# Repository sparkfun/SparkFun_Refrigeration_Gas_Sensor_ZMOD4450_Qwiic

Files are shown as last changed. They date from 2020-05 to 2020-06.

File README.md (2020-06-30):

SparkX Refrigeration Gas Sensor - ZMOD4450 (Qwiic)
========================================

SparkX Refrigeration Gas Sensor - ZMOD4450 (Qwiic)

[*SparkX Refrigeration Gas Sensor - ZMOD4450 (Qwiic) (SPX-16677)*](https://www.sparkfun.com/products/16677)

The ZMOD4450 from Renesas is a refrigeration air quality sensor designed to measure gases typically emitted during food ripening and rotting. The sensor measures ethlyene, amines and volatile sulfur compounds and reports the data via I<sup>2</sup>C. This breakout from SparkX uses the Qwiic system to easily add this sensor into your Qwiic chain. 

Feel like supporting open-source hardware? Buy a [board](https://www.sparkfun.com/products/16677) from SparkFun!

Repository Contents
-------------------

* **/Documentation** - Data sheets, additional product information
* **/Firmware** - Target Specific I<sup>2</sup>C and Low Level Functions
* **/Hardware** - Eagle design files (.brd, .sch)
* **/Production** - Production panel files (.brd)

Product Versions
----------------
* [SPX-16677](https://www.sparkfun.com/products/16677)- Original SparkX release of the Refrigeration Gas Sensor - ZMOD4450

License Information
-------------------

This product is _**open source**_! 

Please review the LICENSE.md file for license information. 

If you have any questions or concerns on licensing, please contact technical support on our [SparkFun forums](https://forum.sparkfun.com/viewforum.php?f=152).

Distributed as-is; no warranty is given.

- Your friends at SparkFun.

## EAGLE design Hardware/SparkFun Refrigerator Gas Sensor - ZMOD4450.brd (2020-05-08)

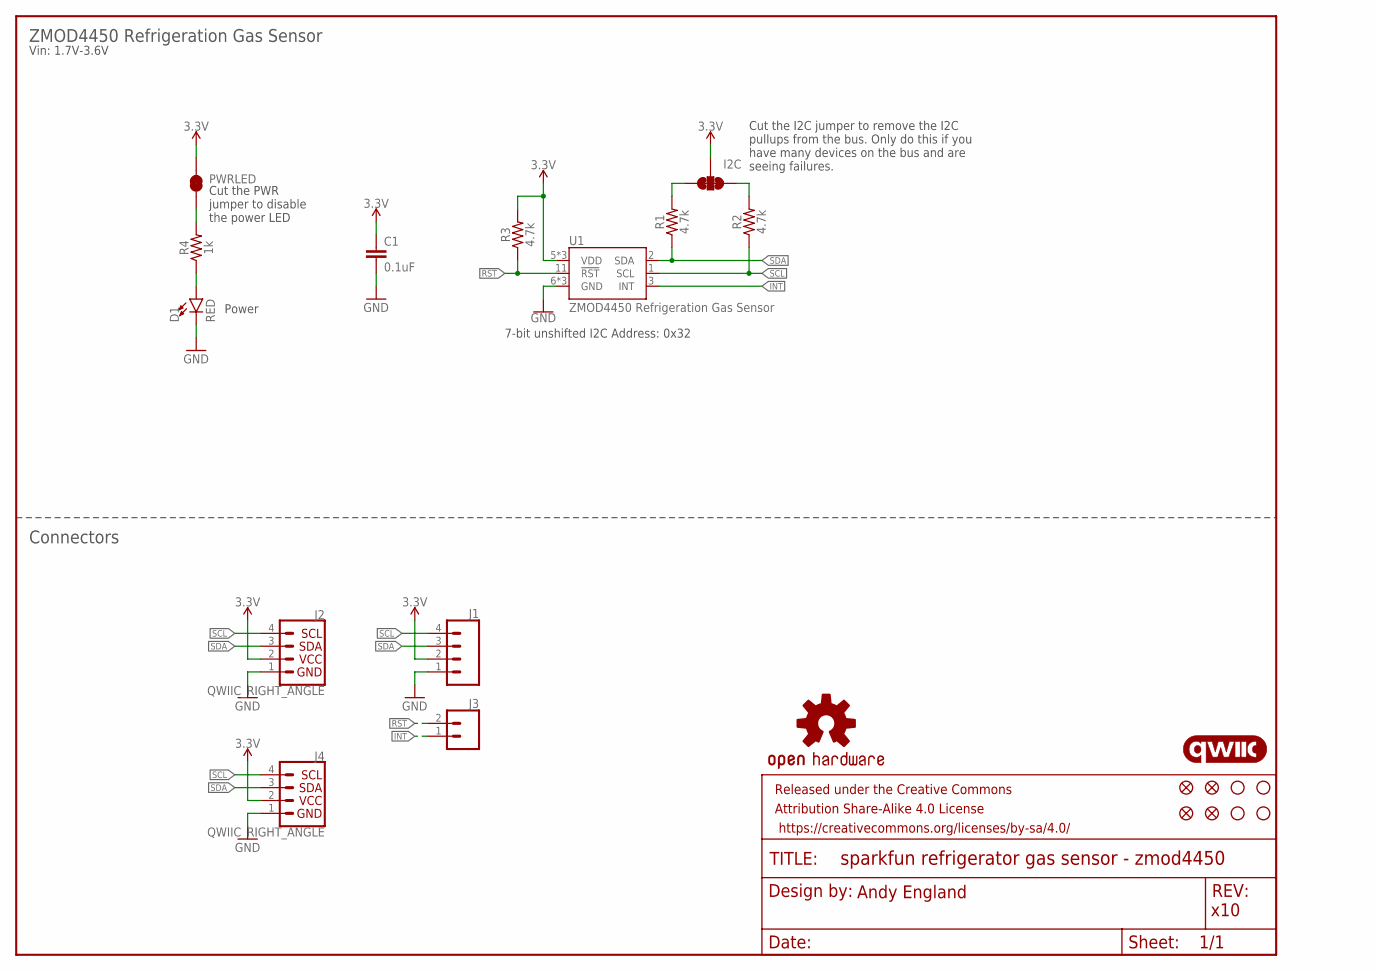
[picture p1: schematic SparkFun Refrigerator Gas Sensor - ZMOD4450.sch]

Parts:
C1: 0.1uF; 0603
D1: RED; LED-0603
FD1, FD2, FD3, FD4: FIDUCIALUFIDUCIAL; FIDUCIAL-MICRO
FRAME1: FRAME-LETTER; CREATIVE_COMMONS
H1, H2, H3, H4: STAND-OFF
I2C: JUMPER-SMT_3_2-NC_TRACE_SILK; SMT-JUMPER_3_2-NC_TRACE_SILK
J1: CONN_041X04_NO_SILK; 1X04_NO_SILK
J2, J4: QWIIC_RIGHT_ANGLE; JST04_1MM_RA
J3: CONN_021X02_NO_SILK; 1X02_NO_SILK
LOGO1: OSHW-LOGOS; OSHW-LOGO-S
LOGO2: QWIIC_LOGO_5MM; QWIIC_5MM
PWRLED: JUMPER-SMT_2_NC_TRACE_SILK; SMT-JUMPER_2_NC_TRACE_SILK
R1, R2, R3: 4.7k; 0603
R4: 1k; 0603
U1: ZMOD4450 Refrigeration Gas Sensor; LGA-12-3X3

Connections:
3.3V: C1.1, I2C.2, J1.2, J2.2, J4.2, PWRLED.2, R3.2, U1.5 (VDD), U1.10 (VDD), U1.12 (VDD)
!RST: J3.2, R3.1, U1.11 (!RST)
GND: C1.2, D1.C, J1.1, J2.1, J4.1, U1.6 (GND), U1.7 (GND), U1.9 (GND)
INT: J3.1, U1.3 (INT)
unnamed: I2C.3, R1.2
unnamed: D1.A, R4.1
unnamed: I2C.1, R2.2
unnamed: PWRLED.1, R4.2
SCL: J1.4, J2.4, J4.4, R2.1, U1.1 (SCL)
SDA: J1.3, J2.3, J4.3, R1.1, U1.2 (SDA)

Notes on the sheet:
Andy England
x10
Power
Connectors
Cut the PWR jumper to disable the power LED
ZMOD4450 Refrigeration Gas Sensor
Vin: 1.7V-3.6V
7-bit unshifted I2C Address: 0x32
Cut the I2C jumper to remove the I2C pullups from the bus. Only do this if you have many devices on the bus and are seeing failures.

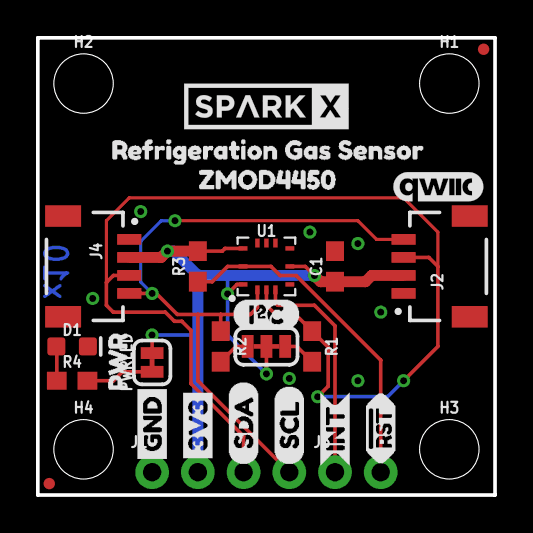
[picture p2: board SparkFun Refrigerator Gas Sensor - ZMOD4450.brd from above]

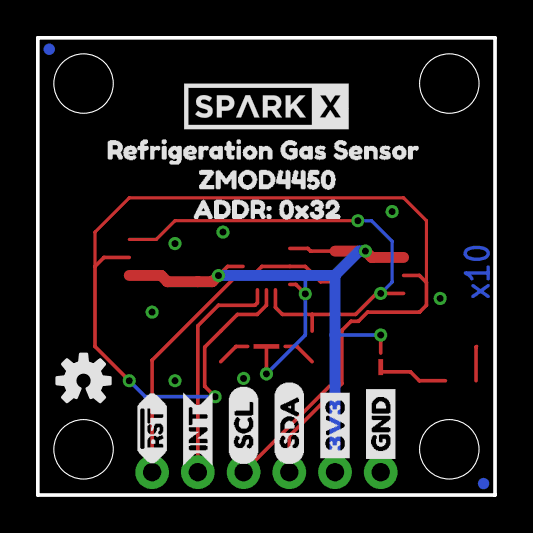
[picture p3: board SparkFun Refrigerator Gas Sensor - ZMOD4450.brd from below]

Board: 2 copper layers, 25.4 x 25.4 mm, 46 parts (13 on the bottom side), 10 nets.

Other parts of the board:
U$1, U$2: GND_P
U$3, U$20: ZMOD44501
U$4, U$14: INT_O
U$5, U$6: 3V3_P
U$7, U$8: SDA_IO
U$9, U$10: SCL_IO
U$11: I2C
U$12: PWR_TO
U$13, U$16: !RST_I
U$15, U$17: REFRIGERATION_GAS_SENSOR0
U$18, U$19: SPARKX-MEDIUM
U$21: ADDR#_0X320
U$22: PRODUCTION_INSTRUCTIONS

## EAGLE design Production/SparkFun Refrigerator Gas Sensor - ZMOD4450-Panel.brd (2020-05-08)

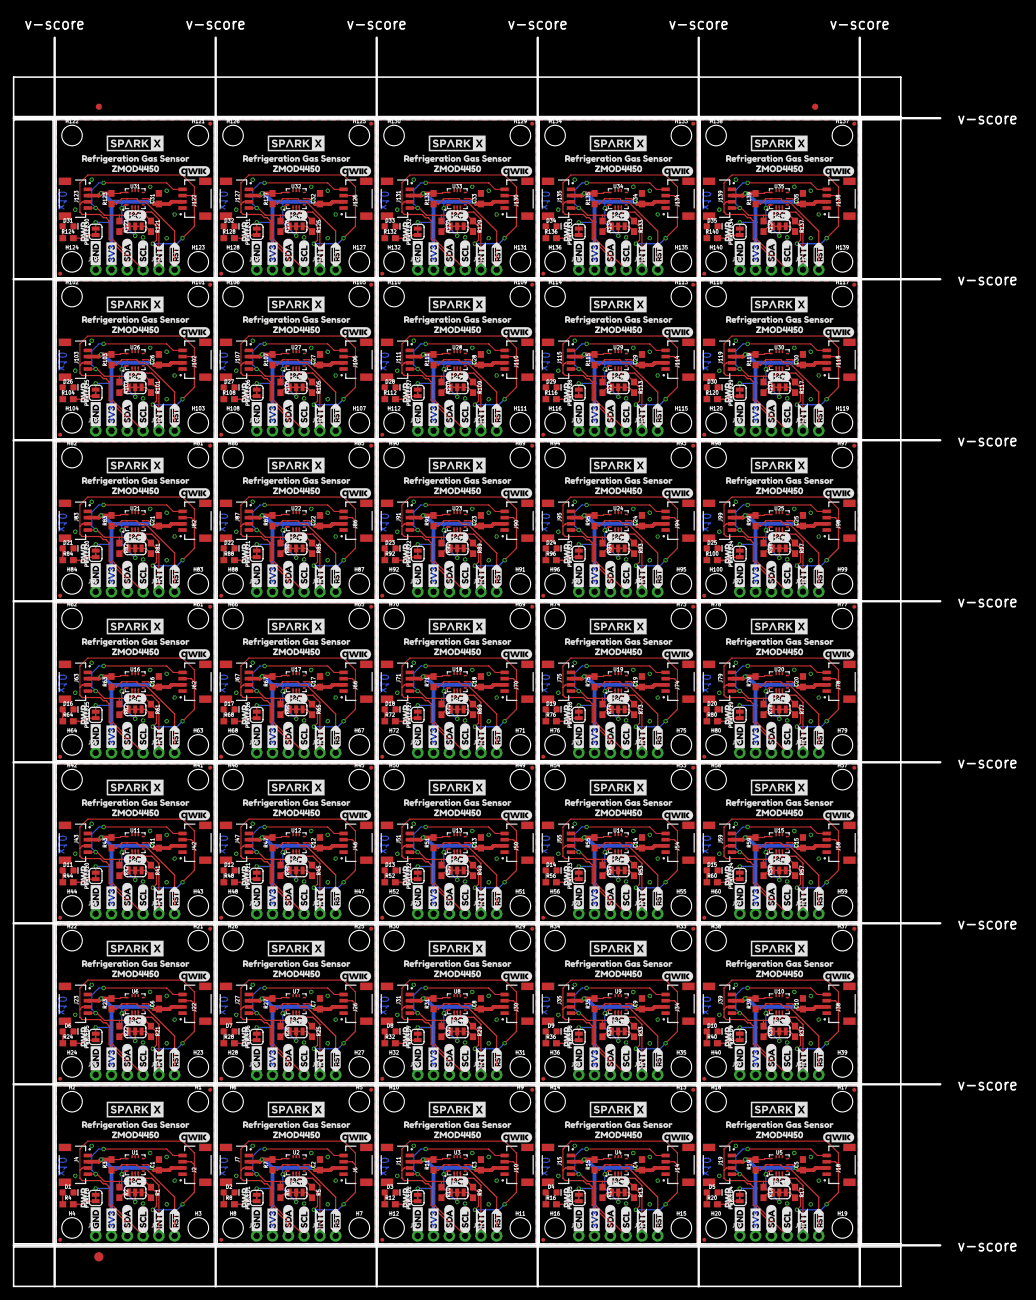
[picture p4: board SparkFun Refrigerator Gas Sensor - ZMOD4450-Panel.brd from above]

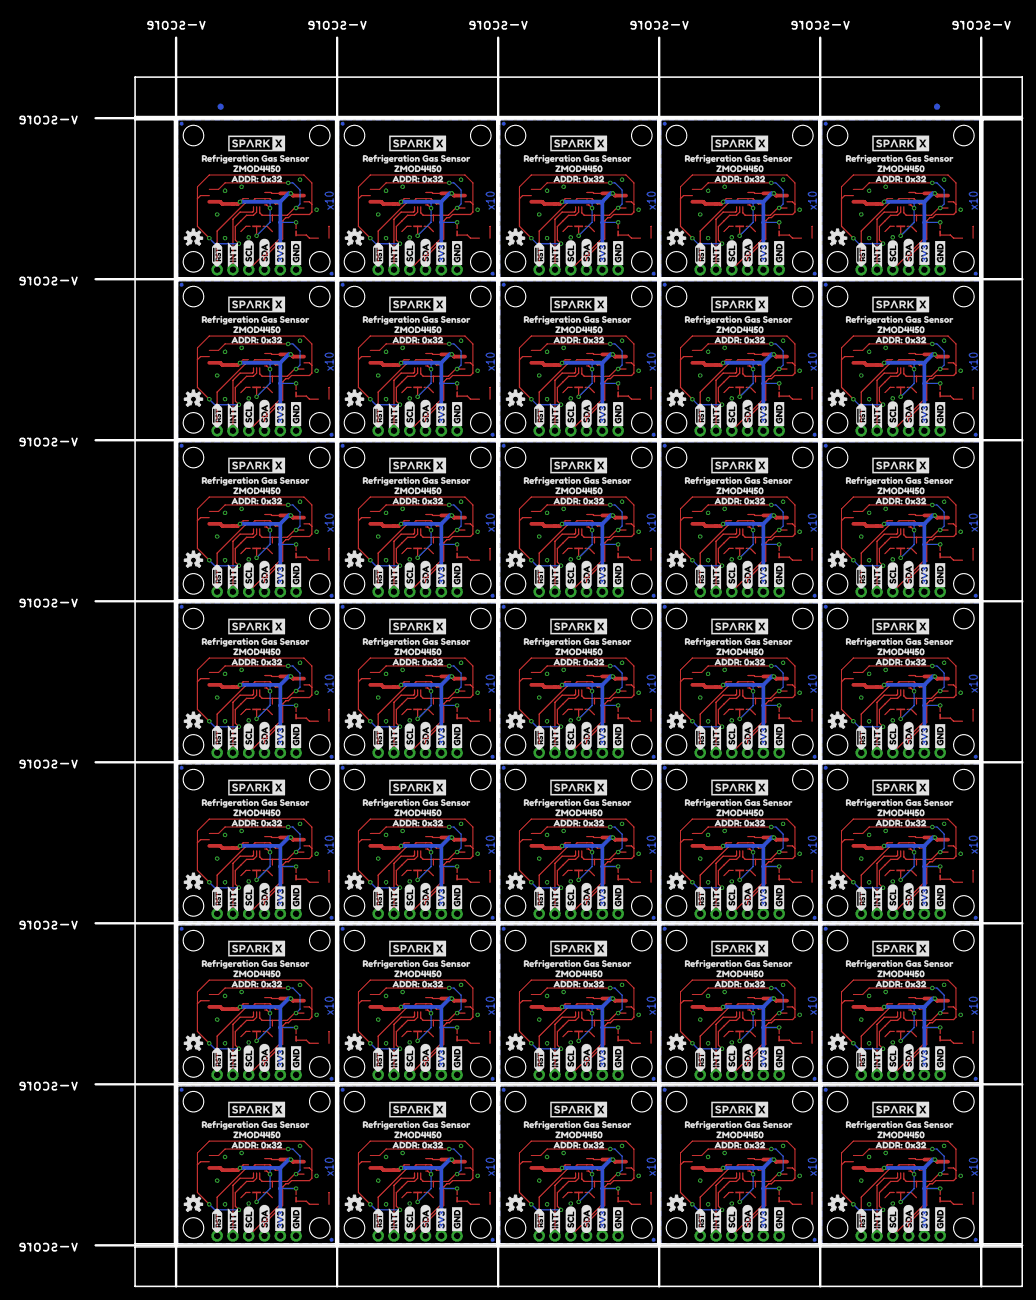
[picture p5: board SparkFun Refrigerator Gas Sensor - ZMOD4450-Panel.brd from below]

Board: 2 copper layers, 149.1 x 200.9 mm, 1615 parts (457 on the bottom side), 350 nets.

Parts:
C1, C2, C3, C4, C5, C6, C7, C8, C9, C10, C11, C12, C13, C14, C15, C16, C17, C18, C19, C20, C21, C22, C23, C24, C25, C26, C27, C28, C29, C30, C31, C32, C33, C34, C35: 0.1uF; 0603
D1, D2, D3, D4, D5, D6, D7, D8, D9, D10, D11, D12, D13, D14, D15, D16, D17, D18, D19, D20, D21, D22, D23, D24, D25, D26, D27, D28, D29, D30, D31, D32, D33, D34, D35: RED; LED-0603
E$1, E$2, E$3, E$4: FIDUCIAL-1X2
E$5: FIDUCIAL-1.5X3
FD1, FD2, FD3, FD4, FD5, FD6, FD7, FD8, FD9, FD10, FD11, FD12, FD13, FD14, FD15, FD16, FD17, FD18, FD19, FD20, FD21, FD22, FD23, FD24, FD25, FD26, FD27, FD28, FD29, FD30, FD31, FD32, FD33, FD34, FD35, FD36, FD37, FD38, FD39, FD40, FD41, FD42, FD43, FD44, FD45, FD46, FD47, FD48, FD49, FD50, FD51, FD52, FD53, FD54, FD55, FD56, FD57, FD58, FD59, FD60, FD61, FD62, FD63, FD64, FD65, FD66, FD67, FD68, FD69, FD70, FD71, FD72, FD73, FD74, FD75, FD76, FD77, FD78, FD79, FD80, FD81, FD82, FD83, FD84, FD85, FD86, FD87, FD88, FD89, FD90, FD91, FD92, FD93, FD94, FD95, FD96, FD97, FD98, FD99, FD100, FD101, FD102, FD103, FD104, FD105, FD106, FD107, FD108, FD109, FD110, FD111, FD112, FD113, FD114, FD115, FD116, FD117, FD118, FD119, FD120, FD121, FD122, FD123, FD124, FD125, FD126, FD127, FD128, FD129, FD130, FD131, FD132, FD133, FD134, FD135, FD136, FD137, FD138, FD139, FD140: FIDUCIALUFIDUCIAL; FIDUCIAL-MICRO
FRAME1, FRAME2, FRAME3, FRAME4, FRAME5, FRAME6, FRAME7, FRAME8, FRAME9, FRAME10, FRAME11, FRAME12, FRAME13, FRAME14, FRAME15, FRAME16, FRAME17, FRAME18, FRAME19, FRAME20, FRAME21, FRAME22, FRAME23, FRAME24, FRAME25, FRAME26, FRAME27, FRAME28, FRAME29, FRAME30, FRAME31, FRAME32, FRAME33, FRAME34, FRAME35: FRAME-LETTER; CREATIVE_COMMONS
H1, H2, H3, H4, H5, H6, H7, H8, H9, H10, H11, H12, H13, H14, H15, H16, H17, H18, H19, H20, H21, H22, H23, H24, H25, H26, H27, H28, H29, H30, H31, H32, H33, H34, H35, H36, H37, H38, H39, H40, H41, H42, H43, H44, H45, H46, H47, H48, H49, H50, H51, H52, H53, H54, H55, H56, H57, H58, H59, H60, H61, H62, H63, H64, H65, H66, H67, H68, H69, H70, H71, H72, H73, H74, H75, H76, H77, H78, H79, H80, H81, H82, H83, H84, H85, H86, H87, H88, H89, H90, H91, H92, H93, H94, H95, H96, H97, H98, H99, H100, H101, H102, H103, H104, H105, H106, H107, H108, H109, H110, H111, H112, H113, H114, H115, H116, H117, H118, H119, H120, H121, H122, H123, H124, H125, H126, H127, H128, H129, H130, H131, H132, H133, H134, H135, H136, H137, H138, H139, H140: STAND-OFF
I2C, I2C1, I2C2, I2C3, I2C4, I2C5, I2C6, I2C7, I2C8, I2C9, I2C10, I2C11, I2C12, I2C13, I2C14, I2C15, I2C16, I2C17, I2C18, I2C19, I2C20, I2C21, I2C22, I2C23, I2C24, I2C25, I2C26, I2C27, I2C28, I2C29, I2C30, I2C31, I2C32, I2C33, I2C34: JUMPER-SMT_3_2-NC_TRACE_SILK; SMT-JUMPER_3_2-NC_TRACE_SILK
J1, J5, J9, J13, J17, J21, J25, J29, J33, J37, J41, J45, J49, J53, J57, J61, J65, J69, J73, J77, J81, J85, J89, J93, J97, J101, J105, J109, J113, J117, J121, J125, J129, J133, J137: 1X04_NO_SILK
J2, J4, J6, J7, J10, J11, J14, J15, J18, J19, J22, J23, J26, J27, J30, J31, J34, J35, J38, J39, J42, J43, J46, J47, J50, J51, J54, J55, J58, J59, J62, J63, J66, J67, J70, J71, J74, J75, J78, J79, J82, J83, J86, J87, J90, J91, J94, J95, J98, J99, J102, J103, J106, J107, J110, J111, J114, J115, J118, J119, J122, J123, J126, J127, J130, J131, J134, J135, J138, J139: QWIIC_RIGHT_ANGLE; JST04_1MM_RA
J3, J8, J12, J16, J20, J24, J28, J32, J36, J40, J44, J48, J52, J56, J60, J64, J68, J72, J76, J80, J84, J88, J92, J96, J100, J104, J108, J112, J116, J120, J124, J128, J132, J136, J140: 1X02_NO_SILK
LOGO1, LOGO3, LOGO5, LOGO7, LOGO9, LOGO11, LOGO13, LOGO15, LOGO17, LOGO19, LOGO21, LOGO23, LOGO25, LOGO27, LOGO29, LOGO31, LOGO33, LOGO35, LOGO37, LOGO39, LOGO41, LOGO43, LOGO45, LOGO47, LOGO49, LOGO51, LOGO53, LOGO55, LOGO57, LOGO59, LOGO61, LOGO63, LOGO65, LOGO67, LOGO69: OSHW-LOGOS; OSHW-LOGO-S
LOGO2, LOGO4, LOGO6, LOGO8, LOGO10, LOGO12, LOGO14, LOGO16, LOGO18, LOGO20, LOGO22, LOGO24, LOGO26, LOGO28, LOGO30, LOGO32, LOGO34, LOGO36, LOGO38, LOGO40, LOGO42, LOGO44, LOGO46, LOGO48, LOGO50, LOGO52, LOGO54, LOGO56, LOGO58, LOGO60, LOGO62, LOGO64, LOGO66, LOGO68, LOGO70: QWIIC_LOGO_5MM; QWIIC_5MM
PWRLED, PWRLED1, PWRLED2, PWRLED3, PWRLED4, PWRLED5, PWRLED6, PWRLED7, PWRLED8, PWRLED9, PWRLED10, PWRLED11, PWRLED12, PWRLED13, PWRLED14, PWRLED15, PWRLED16, PWRLED17, PWRLED18, PWRLED19, PWRLED20, PWRLED21, PWRLED22, PWRLED23, PWRLED24, PWRLED25, PWRLED26, PWRLED27, PWRLED28, PWRLED29, PWRLED30, PWRLED31, PWRLED32, PWRLED33, PWRLED34: JUMPER-SMT_2_NC_TRACE_SILK; SMT-JUMPER_2_NC_TRACE_SILK
R1, R2, R3, R5, R6, R7, R9, R10, R11, R13, R14, R15, R17, R18, R19, R21, R22, R23, R25, R26, R27, R29, R30, R31, R33, R34, R35, R37, R38, R39, R41, R42, R43, R45, R46, R47, R49, R50, R51, R53, R54, R55, R57, R58, R59, R61, R62, R63, R65, R66, R67, R69, R70, R71, R73, R74, R75, R77, R78, R79, R81, R82, R83, R85, R86, R87, R89, R90, R91, R93, R94, R95, R97, R98, R99, R101, R102, R103, R105, R106, R107, R109, R110, R111, R113, R114, R115, R117, R118, R119, R121, R122, R123, R125, R126, R127, R129, R130, R131, R133, R134, R135, R137, R138, R139: 4.7k; 0603
R4, R8, R12, R16, R20, R24, R28, R32, R36, R40, R44, R48, R52, R56, R60, R64, R68, R72, R76, R80, R84, R88, R92, R96, R100, R104, R108, R112, R116, R120, R124, R128, R132, R136, R140: 1k; 0603
U1, U2, U3, U4, U5, U6, U7, U8, U9, U10, U11, U12, U13, U14, U15, U16, U17, U18, U19, U20, U21, U22, U23, U24, U25, U26, U27, U28, U29, U30, U31, U32, U33, U34, U35: ZMOD4450 Refrigeration Gas Sensor; LGA-12-3X3
U$1, U$2, U$23, U$24, U$45, U$46, U$67, U$68, U$89, U$90, U$111, U$112, U$133, U$134, U$155, U$156, U$177, U$178, U$199, U$200, U$221, U$222, U$243, U$244, U$265, U$266, U$287, U$288, U$309, U$310, U$331, U$332, U$353, U$354, U$375, U$376, U$397, U$398, U$419, U$420, U$441, U$442, U$463, U$464, U$485, U$486, U$507, U$508, U$529, U$530, U$551, U$552, U$573, U$574, U$595, U$596, U$617, U$618, U$639, U$640, U$661, U$662, U$683, U$684, U$705, U$706, U$727, U$728, U$749, U$750: GND_P
U$3, U$20, U$38, U$42, U$60, U$64, U$82, U$86, U$104, U$108, U$126, U$130, U$148, U$152, U$170, U$174, U$192, U$196, U$214, U$218, U$236, U$240, U$258, U$262, U$280, U$284, U$302, U$306, U$324, U$328, U$346, U$350, U$368, U$372, U$390, U$394, U$412, U$416, U$434, U$438, U$456, U$460, U$478, U$482, U$500, U$504, U$522, U$526, U$544, U$548, U$566, U$570, U$588, U$592, U$610, U$614, U$632, U$636, U$654, U$658, U$676, U$680, U$698, U$702, U$720, U$724, U$742, U$746, U$764, U$768: ZMOD44501
U$4, U$14, U$39, U$40, U$61, U$62, U$83, U$84, U$105, U$106, U$127, U$128, U$149, U$150, U$171, U$172, U$193, U$194, U$215, U$216, U$237, U$238, U$259, U$260, U$281, U$282, U$303, U$304, U$325, U$326, U$347, U$348, U$369, U$370, U$391, U$392, U$413, U$414, U$435, U$436, U$457, U$458, U$479, U$480, U$501, U$502, U$523, U$524, U$545, U$546, U$567, U$568, U$589, U$590, U$611, U$612, U$633, U$634, U$655, U$656, U$677, U$678, U$699, U$700, U$721, U$722, U$743, U$744, U$765, U$766: INT_O
U$5, U$6, U$25, U$26, U$47, U$48, U$69, U$70, U$91, U$92, U$113, U$114, U$135, U$136, U$157, U$158, U$179, U$180, U$201, U$202, U$223, U$224, U$245, U$246, U$267, U$268, U$289, U$290, U$311, U$312, U$333, U$334, U$355, U$356, U$377, U$378, U$399, U$400, U$421, U$422, U$443, U$444, U$465, U$466, U$487, U$488, U$509, U$510, U$531, U$532, U$553, U$554, U$575, U$576, U$597, U$598, U$619, U$620, U$641, U$642, U$663, U$664, U$685, U$686, U$707, U$708, U$729, U$730, U$751, U$752: 3V3_P
U$7, U$8, U$27, U$28, U$49, U$50, U$71, U$72, U$93, U$94, U$115, U$116, U$137, U$138, U$159, U$160, U$181, U$182, U$203, U$204, U$225, U$226, U$247, U$248, U$269, U$270, U$291, U$292, U$313, U$314, U$335, U$336, U$357, U$358, U$379, U$380, U$401, U$402, U$423, U$424, U$445, U$446, U$467, U$468, U$489, U$490, U$511, U$512, U$533, U$534, U$555, U$556, U$577, U$578, U$599, U$600, U$621, U$622, U$643, U$644, U$665, U$666, U$687, U$688, U$709, U$710, U$731, U$732, U$753, U$754: SDA_IO
U$9, U$10, U$29, U$30, U$51, U$52, U$73, U$74, U$95, U$96, U$117, U$118, U$139, U$140, U$161, U$162, U$183, U$184, U$205, U$206, U$227, U$228, U$249, U$250, U$271, U$272, U$293, U$294, U$315, U$316, U$337, U$338, U$359, U$360, U$381, U$382, U$403, U$404, U$425, U$426, U$447, U$448, U$469, U$470, U$491, U$492, U$513, U$514, U$535, U$536, U$557, U$558, U$579, U$580, U$601, U$602, U$623, U$624, U$645, U$646, U$667, U$668, U$689, U$690, U$711, U$712, U$733, U$734, U$755, U$756: SCL_IO
U$11, U$31, U$53, U$75, U$97, U$119, U$141, U$163, U$185, U$207, U$229, U$251, U$273, U$295, U$317, U$339, U$361, U$383, U$405, U$427, U$449, U$471, U$493, U$515, U$537, U$559, U$581, U$603, U$625, U$647, U$669, U$691, U$713, U$735, U$757: I2C
U$12, U$32, U$54, U$76, U$98, U$120, U$142, U$164, U$186, U$208, U$230, U$252, U$274, U$296, U$318, U$340, U$362, U$384, U$406, U$428, U$450, U$472, U$494, U$516, U$538, U$560, U$582, U$604, U$626, U$648, U$670, U$692, U$714, U$736, U$758: PWR_TO
U$13, U$16, U$33, U$34, U$55, U$56, U$77, U$78, U$99, U$100, U$121, U$122, U$143, U$144, U$165, U$166, U$187, U$188, U$209, U$210, U$231, U$232, U$253, U$254, U$275, U$276, U$297, U$298, U$319, U$320, U$341, U$342, U$363, U$364, U$385, U$386, U$407, U$408, U$429, U$430, U$451, U$452, U$473, U$474, U$495, U$496, U$517, U$518, U$539, U$540, U$561, U$562, U$583, U$584, U$605, U$606, U$627, U$628, U$649, U$650, U$671, U$672, U$693, U$694, U$715, U$716, U$737, U$738, U$759, U$760: !RST_I
U$15, U$17, U$37, U$41, U$59, U$63, U$81, U$85, U$103, U$107, U$125, U$129, U$147, U$151, U$169, U$173, U$191, U$195, U$213, U$217, U$235, U$239, U$257, U$261, U$279, U$283, U$301, U$305, U$323, U$327, U$345, U$349, U$367, U$371, U$389, U$393, U$411, U$415, U$433, U$437, U$455, U$459, U$477, U$481, U$499, U$503, U$521, U$525, U$543, U$547, U$565, U$569, U$587, U$591, U$609, U$613, U$631, U$635, U$653, U$657, U$675, U$679, U$697, U$701, U$719, U$723, U$741, U$745, U$763, U$767: REFRIGERATION_GAS_SENSOR0
U$18, U$19, U$35, U$36, U$57, U$58, U$79, U$80, U$101, U$102, U$123, U$124, U$145, U$146, U$167, U$168, U$189, U$190, U$211, U$212, U$233, U$234, U$255, U$256, U$277, U$278, U$299, U$300, U$321, U$322, U$343, U$344, U$365, U$366, U$387, U$388, U$409, U$410, U$431, U$432, U$453, U$454, U$475, U$476, U$497, U$498, U$519, U$520, U$541, U$542, U$563, U$564, U$585, U$586, U$607, U$608, U$629, U$630, U$651, U$652, U$673, U$674, U$695, U$696, U$717, U$718, U$739, U$740, U$761, U$762: SPARKX-MEDIUM
U$21, U$43, U$65, U$87, U$109, U$131, U$153, U$175, U$197, U$219, U$241, U$263, U$285, U$307, U$329, U$351, U$373, U$395, U$417, U$439, U$461, U$483, U$505, U$527, U$549, U$571, U$593, U$615, U$637, U$659, U$681, U$703, U$725, U$747, U$769: ADDR#_0X320
U$22, U$44, U$66, U$88, U$110, U$132, U$154, U$176, U$198, U$220, U$242, U$264, U$286, U$308, U$330, U$352, U$374, U$396, U$418, U$440, U$462, U$484, U$506, U$528, U$550, U$572, U$594, U$616, U$638, U$660, U$682, U$704, U$726, U$748, U$770: PRODUCTION_INSTRUCTIONS

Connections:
3.3V: C1.1, I2C.2, J1.2, J2.2, J4.2, PWRLED.2, R3.2, U1.5, U1.10, U1.12
3.3V1: C2.1, I2C1.2, J5.2, J6.2, J7.2, PWRLED1.2, R7.2, U2.5, U2.10, U2.12
3.3V2: C3.1, I2C2.2, J9.2, J10.2, J11.2, PWRLED2.2, R11.2, U3.5, U3.10, U3.12
3.3V3: C4.1, I2C3.2, J13.2, J14.2, J15.2, PWRLED3.2, R15.2, U4.5, U4.10, U4.12
3.3V4: C5.1, I2C4.2, J17.2, J18.2, J19.2, PWRLED4.2, R19.2, U5.5, U5.10, U5.12
3.3V5: C6.1, I2C5.2, J21.2, J22.2, J23.2, PWRLED5.2, R23.2, U6.5, U6.10, U6.12
3.3V6: C7.1, I2C6.2, J25.2, J26.2, J27.2, PWRLED6.2, R27.2, U7.5, U7.10, U7.12
3.3V7: C8.1, I2C7.2, J29.2, J30.2, J31.2, PWRLED7.2, R31.2, U8.5, U8.10, U8.12
3.3V8: C9.1, I2C8.2, J33.2, J34.2, J35.2, PWRLED8.2, R35.2, U9.5, U9.10, U9.12
3.3V9: C10.1, I2C9.2, J37.2, J38.2, J39.2, PWRLED9.2, R39.2, U10.5, U10.10, U10.12
3.3V10: C11.1, I2C10.2, J41.2, J42.2, J43.2, PWRLED10.2, R43.2, U11.5, U11.10, U11.12
3.3V11: C12.1, I2C11.2, J45.2, J46.2, J47.2, PWRLED11.2, R47.2, U12.5, U12.10, U12.12
3.3V12: C13.1, I2C12.2, J49.2, J50.2, J51.2, PWRLED12.2, R51.2, U13.5, U13.10, U13.12
3.3V13: C14.1, I2C13.2, J53.2, J54.2, J55.2, PWRLED13.2, R55.2, U14.5, U14.10, U14.12
3.3V14: C15.1, I2C14.2, J57.2, J58.2, J59.2, PWRLED14.2, R59.2, U15.5, U15.10, U15.12
3.3V15: C16.1, I2C15.2, J61.2, J62.2, J63.2, PWRLED15.2, R63.2, U16.5, U16.10, U16.12
3.3V16: C17.1, I2C16.2, J65.2, J66.2, J67.2, PWRLED16.2, R67.2, U17.5, U17.10, U17.12
3.3V17: C18.1, I2C17.2, J69.2, J70.2, J71.2, PWRLED17.2, R71.2, U18.5, U18.10, U18.12
3.3V18: C19.1, I2C18.2, J73.2, J74.2, J75.2, PWRLED18.2, R75.2, U19.5, U19.10, U19.12
3.3V19: C20.1, I2C19.2, J77.2, J78.2, J79.2, PWRLED19.2, R79.2, U20.5, U20.10, U20.12
3.3V20: C21.1, I2C20.2, J81.2, J82.2, J83.2, PWRLED20.2, R83.2, U21.5, U21.10, U21.12
3.3V21: C22.1, I2C21.2, J85.2, J86.2, J87.2, PWRLED21.2, R87.2, U22.5, U22.10, U22.12
3.3V22: C23.1, I2C22.2, J89.2, J90.2, J91.2, PWRLED22.2, R91.2, U23.5, U23.10, U23.12
3.3V23: C24.1, I2C23.2, J93.2, J94.2, J95.2, PWRLED23.2, R95.2, U24.5, U24.10, U24.12
3.3V24: C25.1, I2C24.2, J97.2, J98.2, J99.2, PWRLED24.2, R99.2, U25.5, U25.10, U25.12
3.3V25: C26.1, I2C25.2, J101.2, J102.2, J103.2, PWRLED25.2, R103.2, U26.5, U26.10, U26.12
3.3V26: C27.1, I2C26.2, J105.2, J106.2, J107.2, PWRLED26.2, R107.2, U27.5, U27.10, U27.12
3.3V27: C28.1, I2C27.2, J109.2, J110.2, J111.2, PWRLED27.2, R111.2, U28.5, U28.10, U28.12
3.3V28: C29.1, I2C28.2, J113.2, J114.2, J115.2, PWRLED28.2, R115.2, U29.5, U29.10, U29.12
3.3V29: C30.1, I2C29.2, J117.2, J118.2, J119.2, PWRLED29.2, R119.2, U30.5, U30.10, U30.12
3.3V30: C31.1, I2C30.2, J121.2, J122.2, J123.2, PWRLED30.2, R123.2, U31.5, U31.10, U31.12
3.3V31: C32.1, I2C31.2, J125.2, J126.2, J127.2, PWRLED31.2, R127.2, U32.5, U32.10, U32.12
3.3V32: C33.1, I2C32.2, J129.2, J130.2, J131.2, PWRLED32.2, R131.2, U33.5, U33.10, U33.12
3.3V33: C34.1, I2C33.2, J133.2, J134.2, J135.2, PWRLED33.2, R135.2, U34.5, U34.10, U34.12
3.3V34: C35.1, I2C34.2, J137.2, J138.2, J139.2, PWRLED34.2, R139.2, U35.5, U35.10, U35.12
!RST: J3.2, R3.1, U1.11
!RST1: J8.2, R7.1, U2.11
!RST2: J12.2, R11.1, U3.11
!RST3: J16.2, R15.1, U4.11
!RST4: J20.2, R19.1, U5.11
!RST5: J24.2, R23.1, U6.11
!RST6: J28.2, R27.1, U7.11
!RST7: J32.2, R31.1, U8.11
!RST8: J36.2, R35.1, U9.11
!RST9: J40.2, R39.1, U10.11
!RST10: J44.2, R43.1, U11.11
!RST11: J48.2, R47.1, U12.11
!RST12: J52.2, R51.1, U13.11
!RST13: J56.2, R55.1, U14.11
!RST14: J60.2, R59.1, U15.11
!RST15: J64.2, R63.1, U16.11
!RST16: J68.2, R67.1, U17.11
!RST17: J72.2, R71.1, U18.11
!RST18: J76.2, R75.1, U19.11
!RST19: J80.2, R79.1, U20.11
!RST20: J84.2, R83.1, U21.11
!RST21: J88.2, R87.1, U22.11
!RST22: J92.2, R91.1, U23.11
!RST23: J96.2, R95.1, U24.11
!RST24: J100.2, R99.1, U25.11
!RST25: J104.2, R103.1, U26.11
!RST26: J108.2, R107.1, U27.11
!RST27: J112.2, R111.1, U28.11
!RST28: J116.2, R115.1, U29.11
!RST29: J120.2, R119.1, U30.11
!RST30: J124.2, R123.1, U31.11
!RST31: J128.2, R127.1, U32.11
!RST32: J132.2, R131.1, U33.11
!RST33: J136.2, R135.1, U34.11
!RST34: J140.2, R139.1, U35.11
GND: C1.2, D1.C, J1.1, J2.1, J4.1, U1.6, U1.7, U1.9
GND1: C2.2, D2.C, J5.1, J6.1, J7.1, U2.6, U2.7, U2.9
GND2: C3.2, D3.C, J9.1, J10.1, J11.1, U3.6, U3.7, U3.9
GND3: C4.2, D4.C, J13.1, J14.1, J15.1, U4.6, U4.7, U4.9
GND4: C5.2, D5.C, J17.1, J18.1, J19.1, U5.6, U5.7, U5.9
GND5: C6.2, D6.C, J21.1, J22.1, J23.1, U6.6, U6.7, U6.9
GND6: C7.2, D7.C, J25.1, J26.1, J27.1, U7.6, U7.7, U7.9
GND7: C8.2, D8.C, J29.1, J30.1, J31.1, U8.6, U8.7, U8.9
GND8: C9.2, D9.C, J33.1, J34.1, J35.1, U9.6, U9.7, U9.9
GND9: C10.2, D10.C, J37.1, J38.1, J39.1, U10.6, U10.7, U10.9
GND10: C11.2, D11.C, J41.1, J42.1, J43.1, U11.6, U11.7, U11.9
GND11: C12.2, D12.C, J45.1, J46.1, J47.1, U12.6, U12.7, U12.9
GND12: C13.2, D13.C, J49.1, J50.1, J51.1, U13.6, U13.7, U13.9
GND13: C14.2, D14.C, J53.1, J54.1, J55.1, U14.6, U14.7, U14.9
GND14: C15.2, D15.C, J57.1, J58.1, J59.1, U15.6, U15.7, U15.9
GND15: C16.2, D16.C, J61.1, J62.1, J63.1, U16.6, U16.7, U16.9
GND16: C17.2, D17.C, J65.1, J66.1, J67.1, U17.6, U17.7, U17.9
GND17: C18.2, D18.C, J69.1, J70.1, J71.1, U18.6, U18.7, U18.9
GND18: C19.2, D19.C, J73.1, J74.1, J75.1, U19.6, U19.7, U19.9
GND19: C20.2, D20.C, J77.1, J78.1, J79.1, U20.6, U20.7, U20.9
GND20: C21.2, D21.C, J81.1, J82.1, J83.1, U21.6, U21.7, U21.9
GND21: C22.2, D22.C, J85.1, J86.1, J87.1, U22.6, U22.7, U22.9
GND22: C23.2, D23.C, J89.1, J90.1, J91.1, U23.6, U23.7, U23.9
GND23: C24.2, D24.C, J93.1, J94.1, J95.1, U24.6, U24.7, U24.9
GND24: C25.2, D25.C, J97.1, J98.1, J99.1, U25.6, U25.7, U25.9
GND25: C26.2, D26.C, J101.1, J102.1, J103.1, U26.6, U26.7, U26.9
GND26: C27.2, D27.C, J105.1, J106.1, J107.1, U27.6, U27.7, U27.9
GND27: C28.2, D28.C, J109.1, J110.1, J111.1, U28.6, U28.7, U28.9
GND28: C29.2, D29.C, J113.1, J114.1, J115.1, U29.6, U29.7, U29.9
GND29: C30.2, D30.C, J117.1, J118.1, J119.1, U30.6, U30.7, U30.9
GND30: C31.2, D31.C, J121.1, J122.1, J123.1, U31.6, U31.7, U31.9
GND31: C32.2, D32.C, J125.1, J126.1, J127.1, U32.6, U32.7, U32.9
GND32: C33.2, D33.C, J129.1, J130.1, J131.1, U33.6, U33.7, U33.9
GND33: C34.2, D34.C, J133.1, J134.1, J135.1, U34.6, U34.7, U34.9
GND34: C35.2, D35.C, J137.1, J138.1, J139.1, U35.6, U35.7, U35.9
INT: J3.1, U1.3
INT1: J8.1, U2.3
INT2: J12.1, U3.3
INT3: J16.1, U4.3
INT4: J20.1, U5.3
INT5: J24.1, U6.3
INT6: J28.1, U7.3
INT7: J32.1, U8.3
INT8: J36.1, U9.3
INT9: J40.1, U10.3
INT10: J44.1, U11.3
INT11: J48.1, U12.3
INT12: J52.1, U13.3
INT13: J56.1, U14.3
INT14: J60.1, U15.3
INT15: J64.1, U16.3
INT16: J68.1, U17.3
INT17: J72.1, U18.3
INT18: J76.1, U19.3
INT19: J80.1, U20.3
INT20: J84.1, U21.3
INT21: J88.1, U22.3
INT22: J92.1, U23.3
INT23: J96.1, U24.3
INT24: J100.1, U25.3
INT25: J104.1, U26.3
INT26: J108.1, U27.3
INT27: J112.1, U28.3
INT28: J116.1, U29.3
INT29: J120.1, U30.3
INT30: J124.1, U31.3
INT31: J128.1, U32.3
INT32: J132.1, U33.3
INT33: J136.1, U34.3
INT34: J140.1, U35.3
unnamed: I2C.3, R1.2
unnamed: D1.A, R4.1
unnamed: I2C.1, R2.2
unnamed: PWRLED.1, R4.2
unnamed: I2C1.3, R5.2
unnamed: I2C1.1, R6.2
unnamed: D2.A, R8.1
unnamed: PWRLED1.1, R8.2
unnamed: I2C2.3, R9.2
unnamed: I2C2.1, R10.2
unnamed: D3.A, R12.1
unnamed: PWRLED2.1, R12.2
unnamed: I2C3.3, R13.2
unnamed: I2C3.1, R14.2
unnamed: D4.A, R16.1
unnamed: PWRLED3.1, R16.2
unnamed: I2C4.3, R17.2
unnamed: I2C4.1, R18.2
unnamed: D5.A, R20.1
unnamed: PWRLED4.1, R20.2
unnamed: I2C5.3, R21.2
unnamed: I2C5.1, R22.2
unnamed: D6.A, R24.1
unnamed: PWRLED5.1, R24.2
unnamed: I2C6.3, R25.2
unnamed: I2C6.1, R26.2
unnamed: D7.A, R28.1
unnamed: PWRLED6.1, R28.2
unnamed: I2C7.3, R29.2
unnamed: I2C7.1, R30.2
unnamed: D8.A, R32.1
unnamed: PWRLED7.1, R32.2
unnamed: I2C8.3, R33.2
unnamed: I2C8.1, R34.2
unnamed: D9.A, R36.1
unnamed: PWRLED8.1, R36.2
unnamed: I2C9.3, R37.2
unnamed: I2C9.1, R38.2
unnamed: D10.A, R40.1
unnamed: PWRLED9.1, R40.2
unnamed: I2C10.3, R41.2
unnamed: I2C10.1, R42.2
unnamed: D11.A, R44.1
unnamed: PWRLED10.1, R44.2
unnamed: I2C11.3, R45.2
unnamed: I2C11.1, R46.2
unnamed: D12.A, R48.1
unnamed: PWRLED11.1, R48.2
unnamed: I2C12.3, R49.2
unnamed: I2C12.1, R50.2
unnamed: D13.A, R52.1
unnamed: PWRLED12.1, R52.2
unnamed: I2C13.3, R53.2
unnamed: I2C13.1, R54.2
unnamed: D14.A, R56.1
unnamed: PWRLED13.1, R56.2
unnamed: I2C14.3, R57.2
unnamed: I2C14.1, R58.2
unnamed: D15.A, R60.1
unnamed: PWRLED14.1, R60.2
unnamed: I2C15.3, R61.2
unnamed: I2C15.1, R62.2
unnamed: D16.A, R64.1
unnamed: PWRLED15.1, R64.2
unnamed: I2C16.3, R65.2
unnamed: I2C16.1, R66.2
unnamed: D17.A, R68.1
unnamed: PWRLED16.1, R68.2
unnamed: I2C17.3, R69.2
unnamed: I2C17.1, R70.2
unnamed: D18.A, R72.1
unnamed: PWRLED17.1, R72.2
unnamed: I2C18.3, R73.2
unnamed: I2C18.1, R74.2
unnamed: D19.A, R76.1
unnamed: PWRLED18.1, R76.2
unnamed: I2C19.3, R77.2
unnamed: I2C19.1, R78.2
unnamed: D20.A, R80.1
unnamed: PWRLED19.1, R80.2
unnamed: I2C20.3, R81.2
unnamed: I2C20.1, R82.2
unnamed: D21.A, R84.1
unnamed: PWRLED20.1, R84.2
unnamed: I2C21.3, R85.2
unnamed: I2C21.1, R86.2
unnamed: D22.A, R88.1
unnamed: PWRLED21.1, R88.2
unnamed: I2C22.3, R89.2
unnamed: I2C22.1, R90.2
unnamed: D23.A, R92.1
unnamed: PWRLED22.1, R92.2
unnamed: I2C23.3, R93.2
unnamed: I2C23.1, R94.2
unnamed: D24.A, R96.1
unnamed: PWRLED23.1, R96.2
unnamed: I2C24.3, R97.2
unnamed: I2C24.1, R98.2
unnamed: D25.A, R100.1
unnamed: PWRLED24.1, R100.2
unnamed: I2C25.3, R101.2
unnamed: I2C25.1, R102.2
unnamed: D26.A, R104.1
unnamed: PWRLED25.1, R104.2
unnamed: I2C26.3, R105.2
unnamed: I2C26.1, R106.2
unnamed: D27.A, R108.1
unnamed: PWRLED26.1, R108.2
unnamed: I2C27.3, R109.2
unnamed: I2C27.1, R110.2
unnamed: D28.A, R112.1
unnamed: PWRLED27.1, R112.2
unnamed: I2C28.3, R113.2
unnamed: I2C28.1, R114.2
unnamed: D29.A, R116.1
unnamed: PWRLED28.1, R116.2
unnamed: I2C29.3, R117.2
unnamed: I2C29.1, R118.2
unnamed: D30.A, R120.1
unnamed: PWRLED29.1, R120.2
unnamed: I2C30.3, R121.2
unnamed: I2C30.1, R122.2
unnamed: D31.A, R124.1
unnamed: PWRLED30.1, R124.2
unnamed: I2C31.3, R125.2
unnamed: I2C31.1, R126.2
unnamed: D32.A, R128.1
unnamed: PWRLED31.1, R128.2
unnamed: I2C32.3, R129.2
unnamed: I2C32.1, R130.2
unnamed: D33.A, R132.1
unnamed: PWRLED32.1, R132.2
unnamed: I2C33.3, R133.2
unnamed: I2C33.1, R134.2
unnamed: D34.A, R136.1
unnamed: PWRLED33.1, R136.2
unnamed: I2C34.3, R137.2
unnamed: I2C34.1, R138.2
unnamed: D35.A, R140.1
unnamed: PWRLED34.1, R140.2
SCL: J1.4, J2.4, J4.4, R2.1, U1.1
SCL1: J5.4, J6.4, J7.4, R6.1, U2.1
SCL2: J9.4, J10.4, J11.4, R10.1, U3.1
SCL3: J13.4, J14.4, J15.4, R14.1, U4.1
SCL4: J17.4, J18.4, J19.4, R18.1, U5.1
SCL5: J21.4, J22.4, J23.4, R22.1, U6.1
SCL6: J25.4, J26.4, J27.4, R26.1, U7.1
SCL7: J29.4, J30.4, J31.4, R30.1, U8.1
SCL8: J33.4, J34.4, J35.4, R34.1, U9.1
SCL9: J37.4, J38.4, J39.4, R38.1, U10.1
SCL10: J41.4, J42.4, J43.4, R42.1, U11.1
SCL11: J45.4, J46.4, J47.4, R46.1, U12.1
SCL12: J49.4, J50.4, J51.4, R50.1, U13.1
SCL13: J53.4, J54.4, J55.4, R54.1, U14.1
SCL14: J57.4, J58.4, J59.4, R58.1, U15.1
SCL15: J61.4, J62.4, J63.4, R62.1, U16.1
SCL16: J65.4, J66.4, J67.4, R66.1, U17.1
SCL17: J69.4, J70.4, J71.4, R70.1, U18.1
SCL18: J73.4, J74.4, J75.4, R74.1, U19.1
SCL19: J77.4, J78.4, J79.4, R78.1, U20.1
SCL20: J81.4, J82.4, J83.4, R82.1, U21.1
SCL21: J85.4, J86.4, J87.4, R86.1, U22.1
SCL22: J89.4, J90.4, J91.4, R90.1, U23.1
SCL23: J93.4, J94.4, J95.4, R94.1, U24.1
SCL24: J97.4, J98.4, J99.4, R98.1, U25.1
SCL25: J101.4, J102.4, J103.4, R102.1, U26.1
SCL26: J105.4, J106.4, J107.4, R106.1, U27.1
SCL27: J109.4, J110.4, J111.4, R110.1, U28.1
SCL28: J113.4, J114.4, J115.4, R114.1, U29.1
SCL29: J117.4, J118.4, J119.4, R118.1, U30.1
SCL30: J121.4, J122.4, J123.4, R122.1, U31.1
SCL31: J125.4, J126.4, J127.4, R126.1, U32.1
SCL32: J129.4, J130.4, J131.4, R130.1, U33.1
SCL33: J133.4, J134.4, J135.4, R134.1, U34.1
SCL34: J137.4, J138.4, J139.4, R138.1, U35.1
SDA: J1.3, J2.3, J4.3, R1.1, U1.2
SDA1: J5.3, J6.3, J7.3, R5.1, U2.2
SDA2: J9.3, J10.3, J11.3, R9.1, U3.2
SDA3: J13.3, J14.3, J15.3, R13.1, U4.2
SDA4: J17.3, J18.3, J19.3, R17.1, U5.2
SDA5: J21.3, J22.3, J23.3, R21.1, U6.2
SDA6: J25.3, J26.3, J27.3, R25.1, U7.2
SDA7: J29.3, J30.3, J31.3, R29.1, U8.2
SDA8: J33.3, J34.3, J35.3, R33.1, U9.2
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

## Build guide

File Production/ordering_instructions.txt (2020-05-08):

panel size, 143x188mm
PCB thickness, 1.6mm
number of layers, 2
soldermask color, Black
silkscreen color, White
oz copper, 1oz
finish, HASL lead free
stencils, top
pcs per panel, 35
min trace width, 0.1778mm / 0.0070in
min drill size, 0.3810mm / 0.0150in

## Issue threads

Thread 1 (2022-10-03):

Is there any Arduino sample code for ZMOD4450?

rodri16, 2022-10-03:
I can't find, there is only an empty example
`extern "C"{
#include "C:\Users\user\Documents\Arduino\libraries\ZMOD4450\src\main.h"
};

void setup() {
  delay(5000);
  Serial.begin(115200);
  Wire.begin();
  Wire.setClock(100000);
  main();
}

void loop() {

}`

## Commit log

2020-04-27 initial commit/layout
    [SparkFun Refrigerator Gas Sensor (ZMOD4450).brd, SparkFun Refrigerator Gas Sensor (ZMOD4450).sch]
2020-05-06 Checklist changes
    [SparkFun Refrigerator Gas Sensor (ZMOD4450).sch]
2020-05-06 Changing INT silk
    [SparkFun Refrigerator Gas Sensor (ZMOD4450).brd, SparkFun Refrigerator Gas Sensor (ZMOD4450).sch]
2020-05-08 adding initial panel
    [SparkFun Refrigerator Gas Sensor - ZMOD4450-Panel.GBL, SparkFun Refrigerator Gas Sensor - ZMOD4450-Panel.GBO, SparkFun Refrigerator Gas Sensor - ZMOD4450-Panel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]
2020-06-08 cleaning up for launch
    [SparkFun Refrigerator Gas Sensor (ZMOD4450).brd, SparkFun Refrigerator Gas Sensor (ZMOD4450).sch]

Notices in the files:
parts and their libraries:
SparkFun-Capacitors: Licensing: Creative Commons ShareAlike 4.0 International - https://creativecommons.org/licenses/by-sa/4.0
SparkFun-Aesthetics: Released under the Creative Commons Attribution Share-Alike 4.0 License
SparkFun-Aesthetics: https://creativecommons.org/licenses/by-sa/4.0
